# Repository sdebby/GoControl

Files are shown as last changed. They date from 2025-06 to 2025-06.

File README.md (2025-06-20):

# GoControl - ESP32 GoPro remote control

Project start date: 19.10.2024

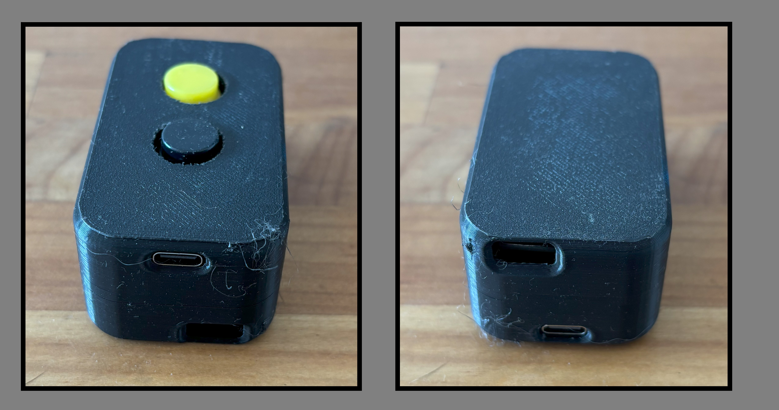
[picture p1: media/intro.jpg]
Overview picture


## Overview

Building a cheap GoPro camera remote control, using Open GoPro API
 
## MRD (Marketing requirement)

 - Creating a simple -easy to use, BLE remote control for GoPro Cameras.
 - up to 2 buttons and LED for operation Indication.
 - Mobile and small size (similar to car remote)
 
### User indications

The remote will indicate the following using build in led:

* On connection - Green LED
* On disconnection - Red LED
* On sending Action Start command - Blue LED
* On sending Camera mode command - Yellow LED
 
## Skill set

 * BLE knowledge.
 * PCB editing.
 * 3D design.
 * 3D printing.
 * Arduino and C++ programming.
 
## BOM (Bill Of Materials):

1. ESP32 C6 dev kit
2. 2 X tact switches.
3. 2 X 330 Ohm resistors.
4. [Charger panel](https://www.aliexpress.com/item/1005005037876729.html?spm=a2g0o.order_list.order_list_main.386.6b881802CcDzO8)
5. LiPo battery 120 mAh.
   
**For R&D:**
1. Wiring.
2. breadboard.

**For production:**
1. PCB manufacturing.
2. 3D printing for enclosure.

## Software:

1. Arduino IDE for coding and uploading to ESP32 C6 board.
2. KiCad for PCB design.
3. Fusion360 for 3D enclosure design

## TSD (Technical Specification)

* Using a BLE to control GoPro camera
[OpenGoPro](https://gopro.github.io/OpenGoPro/ble/index.html)
* Running on ESP32 C6 dev board

## Scheme

1. FOR THE FIRST TIME, AND AFTER INSTALLING NEW FIRMWARE: Insert GoPro camera into [paring model](https://community.gopro.com/s/article/GoPro-Quik-How-To-Pair-Your-Camera?language=en_US#HERO2024)
2. Remote will scan for BLE devices.
3. Remote will connect to the first device that advertise GoPro `serviceUUID` (0xFEA6)
4. On fail connection / disconnection, remote will scan for BLE devices again.
5. Remote will stop scanning and go to deep sleep mode after 3 failed scans.
   1. Remote will wake up on button press.
OnConnection to GoPro camera:
1. Remote will turn BUILTIN LED to Green.
2. On pressing button 1, remote will send Action start command to `COMMAND_REQ_UUID`
3. On releasing button 2, remote will send Action stop command to `COMMAND_REQ_UUID`
4. On pressing button 2, remote will rotate between PhotoMode / VideoMode / TimelapsMode, by sending the correct request to  `COMMAND_REQ_UUID`
5.  The remote will listen to camera reply by registering a listener on  `COMMAND_RSP_UUID` service
OnDisconnection from GoPro camera:
1. Remote will turn BUILTIN LED to Red.
2. Remote will start scanning for GoPro devices again.
3. Remote will go to deep sleep mode after 3 failed scans.

## Schematics

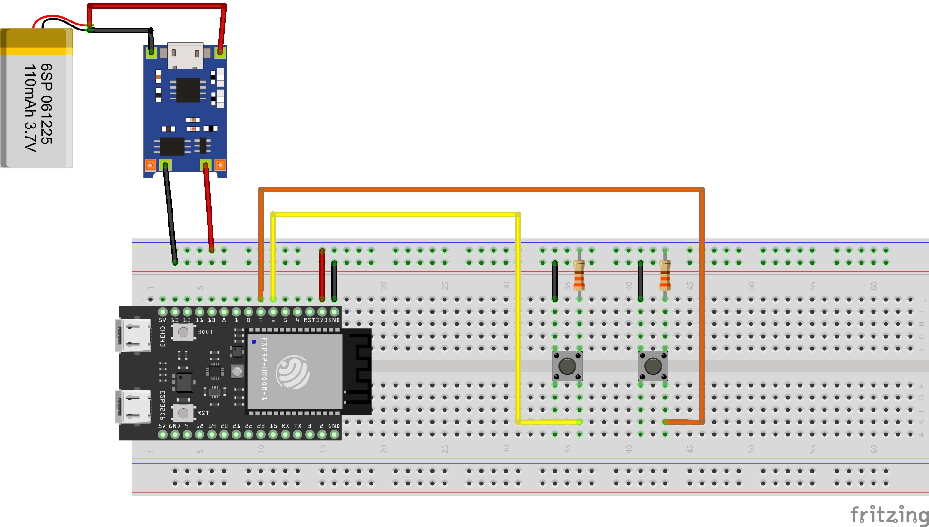
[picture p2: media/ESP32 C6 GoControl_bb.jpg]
Scheme


## PCB

* PCB design using KiCad
* 2 layers PCB
* PCB manufacturing using PCBWay
  
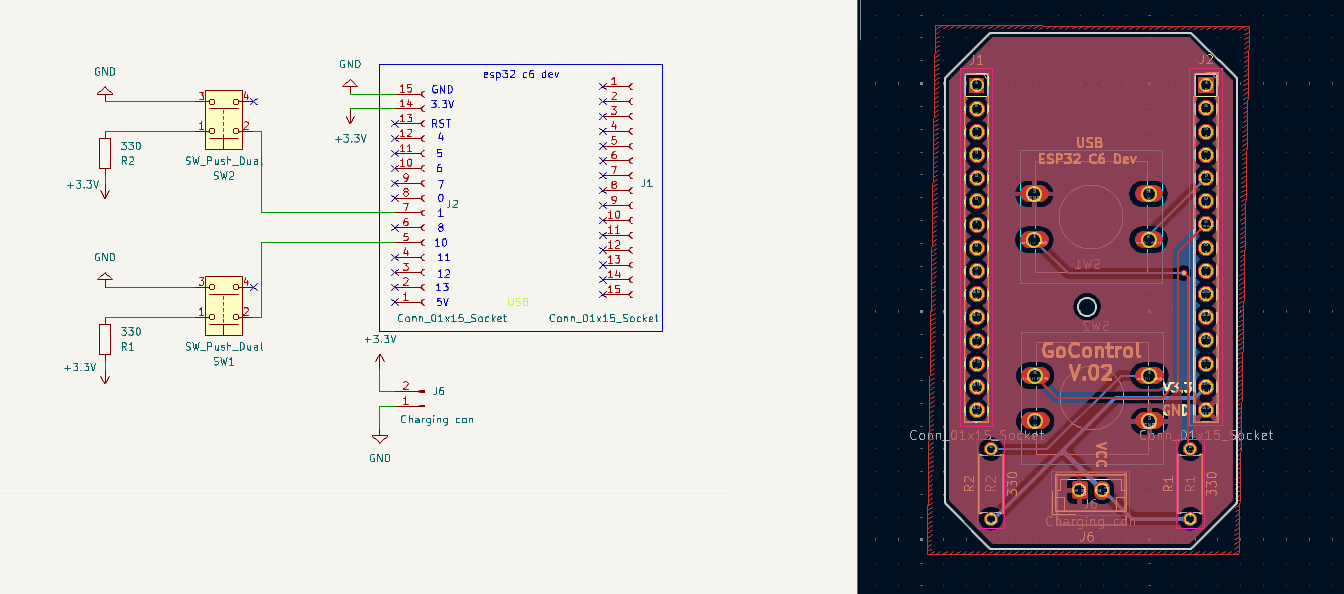
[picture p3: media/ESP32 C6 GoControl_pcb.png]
PCB


## Hardware assembly:

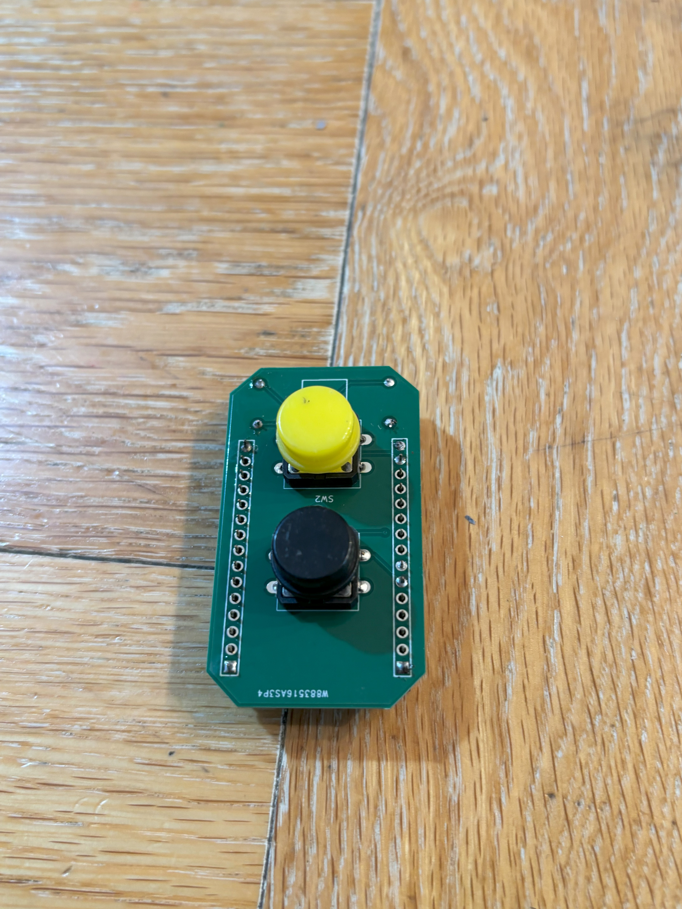
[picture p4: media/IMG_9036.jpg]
Welding components to PCB:


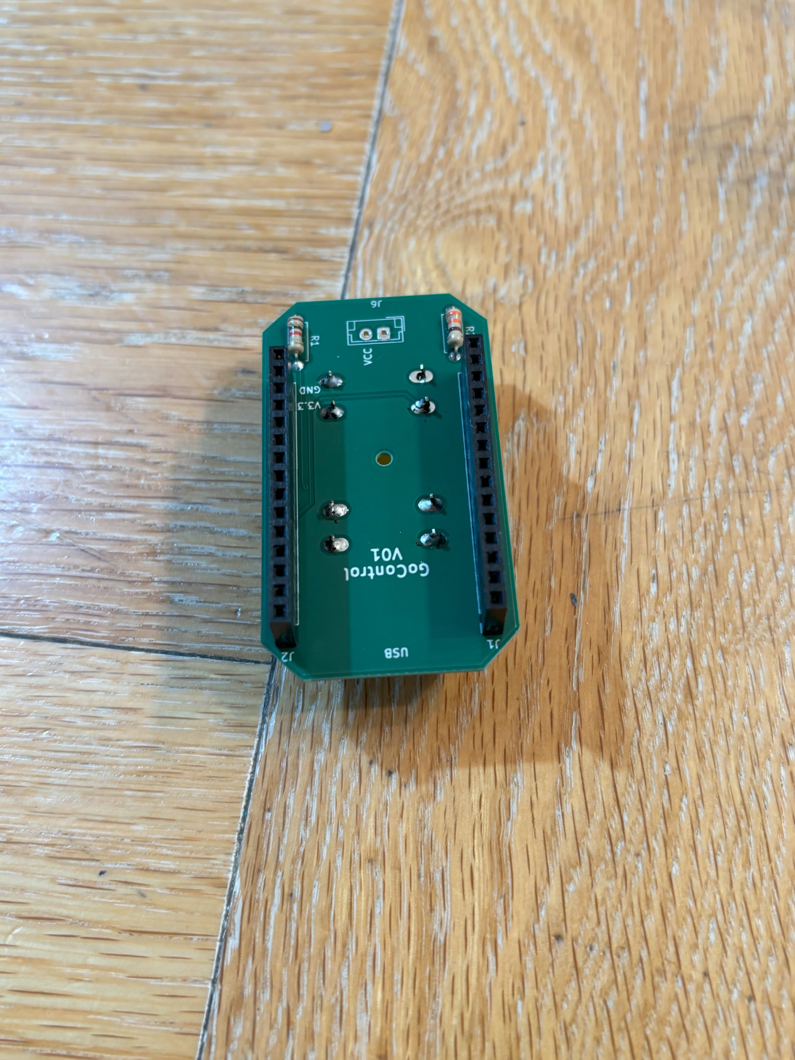
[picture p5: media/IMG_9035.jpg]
Welding components to PCB


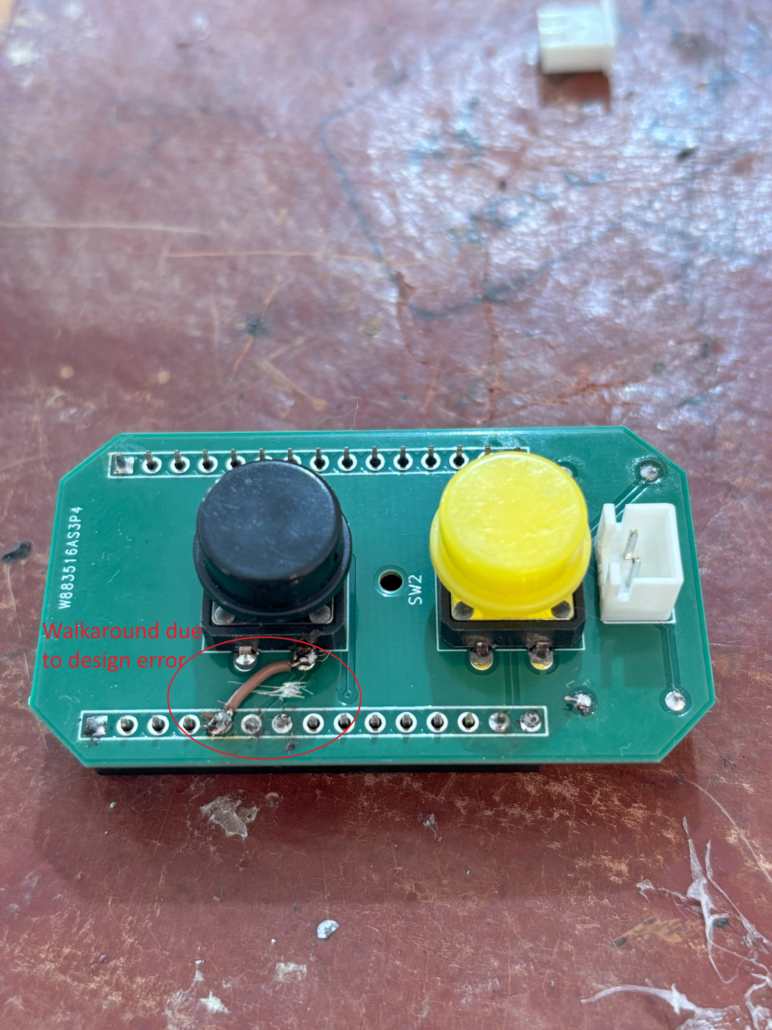
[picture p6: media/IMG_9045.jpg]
Fixing PCB wrong wiring:


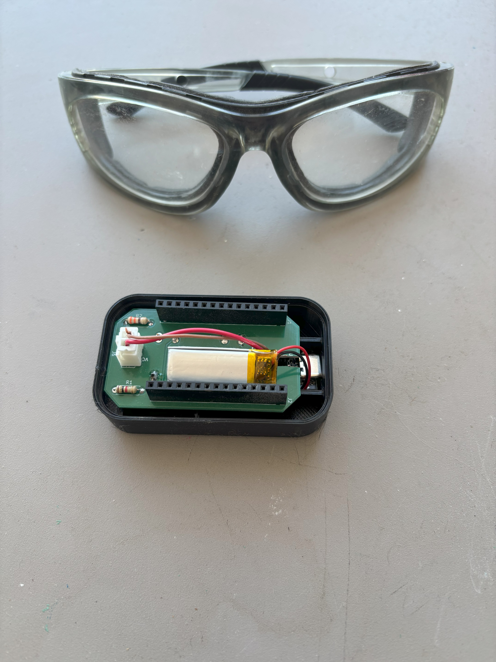
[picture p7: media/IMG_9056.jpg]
Adding cut on PCB to fix ease assembly:


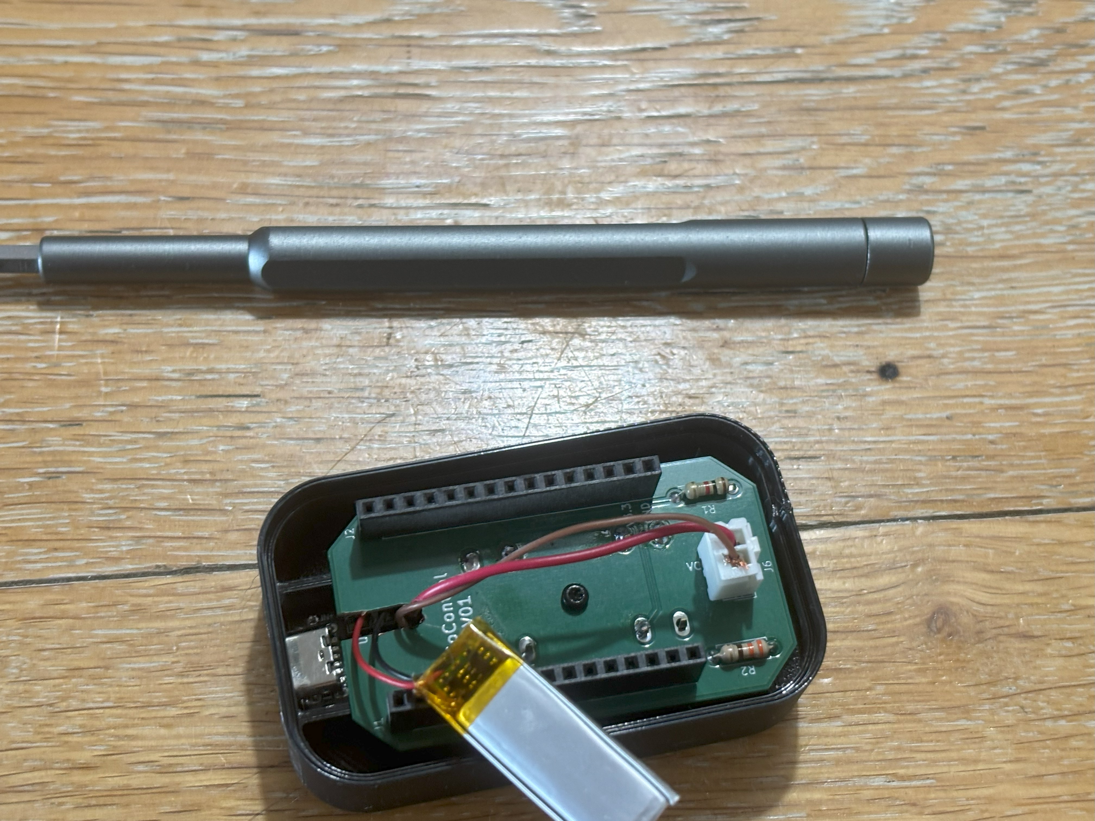
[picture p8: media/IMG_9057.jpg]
Final PCB assembly:


### 3D enclosure design

* using Fusion360
* 3D print using Ender 5 plus with PLA filament.
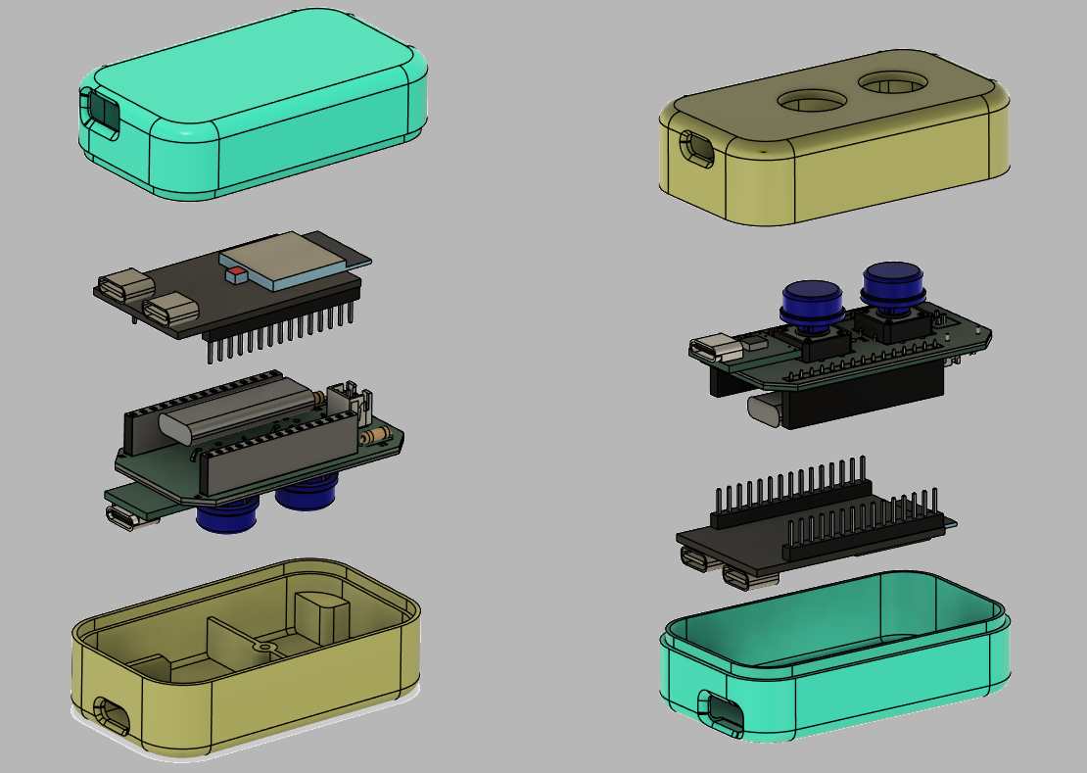
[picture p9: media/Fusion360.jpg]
3D enclosure design


## Video

(https://youtu.be/bjMAEX7DmnI)

## R&D

Coin cell battery capacity:

| Battery | Capacity |
| --- | --- |
|  2016 | 100 mAh |
|  2025 | 170 mAh |
|  2032 | 235 mAh |
|  2450 | 620 mAh |

* Using 2032 battery did not work, as it was not able to power the ESP32 C6 board, I had to use LiPo battery. with 1200 mAh capacity.

### Code fixing

Fixing arduino not displaying BLE device names:
[Fixing library dont support short names](https://github.com/nkolban/esp32-snippets/issues/871)
the file `BLEAdvertisedDevice.cpp` in library :
c:\Users\user1\AppData\Local\Arduino15\packages\esp32\hardware\esp32\3.0.5\libraries\BLE\src\

### Deep sleep

1. deep sleep:
	1. [espressif doc](https://docs.espressif.com/projects/esp-idf/en/latest/esp32c6/api-reference/system/sleep_modes.html)
	2. Wake up on button can be use only on RTC pins
	3. On ESP32-C6: RTC pins are 0-7

## Feedback

If you have any feedback, please reach out to us at mailto:shmulik.debby@gmail.com

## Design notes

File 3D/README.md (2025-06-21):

Project 3D enclosure case files, for 3D FDM printing

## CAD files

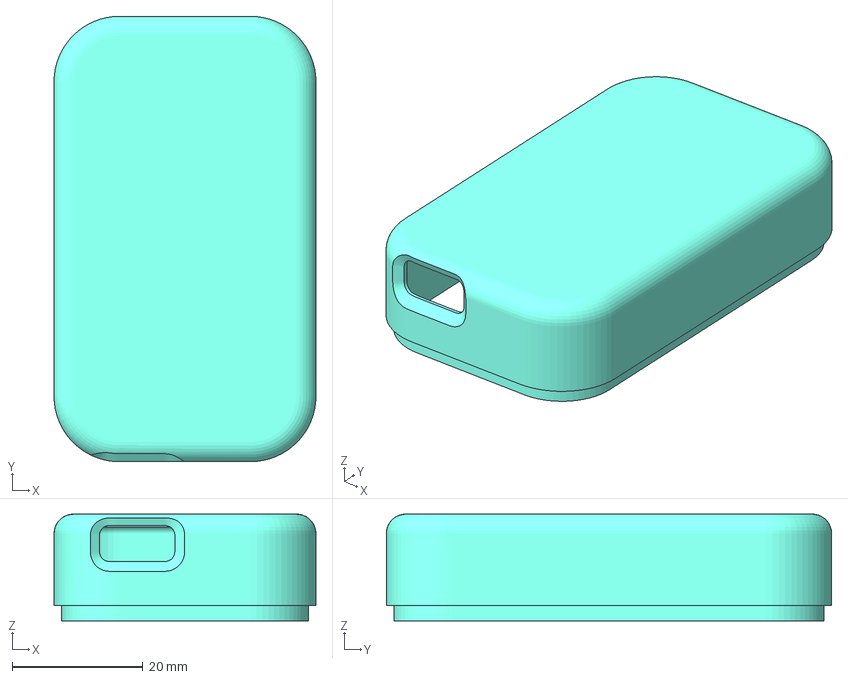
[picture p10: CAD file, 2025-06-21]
3D/Encoder bottom.3mf
40.0 x 68.0 x 16.3 mm

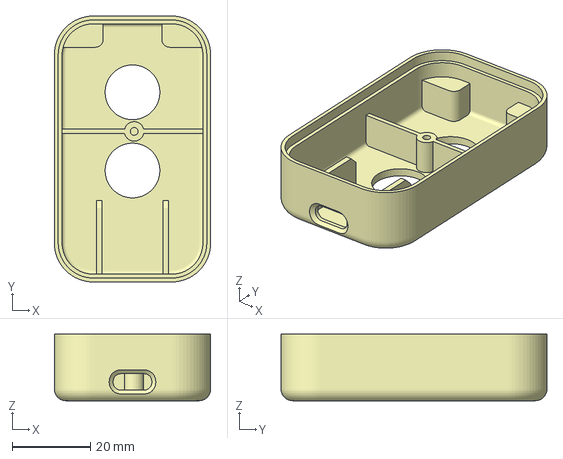
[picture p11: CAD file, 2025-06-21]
3D/Encoder top.3mf
40.0 x 68.0 x 17.0 mm

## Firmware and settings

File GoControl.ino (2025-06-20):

/* 19.10.2024
GoControl - A GoPro remote control camera V.1
*/

#include <BLEDevice.h>
#include <ezButton.h>
#include "driver/rtc_io.h"

#define CONTROL_QUERY_SERVICE_UUID "0000fea6-0000-1000-8000-00805f9b34fb";
uint16_t CONTROL_SERVICE_UUID  = 0xFEA6;
#define INTERNAL_UUID "00002a19-0000-1000-8000-00805f9b34fb"

#define WIFI_AP_SSID_UUID "b5f90002-aa8d-11e3-9046-0002a5d5c51b"
#define WIFI_AP_PASSWORD_UUID "b5f90003-aa8d-11e3-9046-0002a5d5c51b"

#define COMMAND_REQ_UUID "b5f90072-aa8d-11e3-9046-0002a5d5c51b"
#define COMMAND_RSP_UUID "b5f90073-aa8d-11e3-9046-0002a5d5c51b"
#define SETTINGS_REQ_UUID "b5f90074-aa8d-11e3-9046-0002a5d5c51b"
#define SETTINGS_RSP_UUID "b5f90075-aa8d-11e3-9046-0002a5d5c51b"
#define QUERY_REQ_UUID "b5f90076-aa8d-11e3-9046-0002a5d5c51b"
#define QUERY_RSP_UUID "b5f90077-aa8d-11e3-9046-0002a5d5c51b"

#define NETWORK_MANAGEMENT_REQ_UUID "b5f90091-aa8d-11e3-9046-0002a5d5c51b"
#define NETWORK_MANAGEMENT_RSP_UUID "b5f90092-aa8d-11e3-9046-0002a5d5c51b"

bool GoProFound = false;
bool IsConnected = false;
BLEScan *pBLEScan;
int scanTime = 5;  //In seconds
static BLEAdvertisedDevice *GoProAddress;
static BLERemoteCharacteristic *pRemoteCharacteristicREQ; //Request UUID
static BLERemoteCharacteristic *pRemoteCharacteristicRSP; // Responce UUID
byte ActionStart[] = {0x03, 0x01, 0x01, 0x01};  
byte ActionStop[] = {0x03, 0x01, 0x01, 0x00};  

byte PhotoMode[] = {0x04, 0x3E, 0x02, 0x03, 0xE9};  
byte VideoMode[] = {0x04, 0x3E, 0x02, 0x03, 0xE8};  
byte TimelapsMode[] = {0x04, 0x3E, 0x02, 0x03, 0xEA};  
int CamMode = 0; // Camera mode - 0 = Photo, 1 = Video, 2 = Timelaps
int DisconnectCount = 0; //Count no of disconnections
int NoOfScans = 3; // BLE scans before going to deep sleep
int ScanDone = 0; // Number of BLE scans that done

ezButton Button_1(1,INPUT_PULLUP);
ezButton Button_2(10,INPUT_PULLUP);

static BLEUUID serviceUUID(CONTROL_SERVICE_UUID);
static BLEUUID charUUID_REQ(COMMAND_REQ_UUID);
static BLEUUID charUUID_RSP(COMMAND_RSP_UUID);

// Deep sleep parameters
#define BUTTON_PIN_BITMASK(GPIO) (1ULL << GPIO)  // 2 ^ GPIO_NUMBER in hex
#define USE_EXT0_WAKEUP 1               // 1 = EXT0 wakeup, 0 = EXT1 wakeup
#define WAKEUP_GPIO GPIO_NUM_7     // Wateup pin
bool Wakup_RTC_CNTL = false;

// Wakeup reason
void print_wakeup_reason() {
  esp_sleep_wakeup_cause_t wakeup_reason;
  wakeup_reason = esp_sleep_get_wakeup_cause();
  switch (wakeup_reason) {
    case ESP_SLEEP_WAKEUP_EXT1:
      Serial.println("Wakeup caused by external signal using RTC_CNTL");
      Wakup_RTC_CNTL = true;
      break;
    default:
      Serial.printf("Wakeup was not caused by deep sleep: %d\n", wakeup_reason);
      break;
  }
}


class ClientCallback : public BLEClientCallbacks {
  void onConnect(BLEClient *pclient) {
    Serial.println("onCOnnect");
  }

  void onDisconnect(BLEClient *pclient) {
    Serial.println("onDisconnect");
    IsConnected = false;
  }
};

// Notify callback
static void notifyCallback(BLERemoteCharacteristic *pBLERemoteCharacteristic, uint8_t *pData, size_t length, bool isNotify) {
  Serial.print("[*] Notify callback, data length: ");
  Serial.print(length);
  Serial.print(" ,data: ");
  for (int i = 0; i < length ; i++){
    if(pData[i] < 9){
      Serial.print("0");
    }
    Serial.print(pData[i], HEX);
    Serial.print(" ");
  }
  Serial.println();
}

// Connect to BLE Server
void ConnectToBLE() {
  Serial.print("[*] Connecting to: ");
  Serial.println(GoProAddress->getAddress().toString().c_str());
  BLEClient *pClient = BLEDevice::createClient();
  pClient->setClientCallbacks(new ClientCallback());
  BLEDevice::setEncryptionLevel(ESP_BLE_SEC_ENCRYPT);
  pClient->connect(GoProAddress); 
  if (!pClient->isConnected()) { // Check if connected
    Serial.println("[X] Client not connected.");
    return;
  }
  pClient->setMTU(517);  //set client to request maximum MTU from server (default is 23 otherwise)
  Serial.println("[V] Connected to GoPro camera");
  RGBLed('g');
  Serial.println("[*] Attempting to connect to service...");
    
  BLERemoteService *pRemoteService = pClient->getService(serviceUUID);  // Obtain a reference to the service we are after in the remote BLE server.
  if (pRemoteService == nullptr) {
    Serial.print("[X] Failed to find SERVICE UUID: ");
    Serial.println(serviceUUID.toString().c_str());
    pClient->disconnect();
  } else {
    Serial.println("[V] Connected to SERVICE UUID");
    // CONNECTING TO REQUEST uuid
      pRemoteCharacteristicREQ = pRemoteService->getCharacteristic(charUUID_REQ); //request UUID
      if (pRemoteCharacteristicREQ == nullptr) {
        Serial.println("[X] Failed to find REQUEST Characteristic UUID: ");
        pClient->disconnect();
      } else{
        Serial.println("[V] Connected to REQUEST Characteristic UUID");
        IsConnected = true;
      }
    // CONNECTING TO RESPONCE uuid
      pRemoteCharacteristicRSP = pRemoteService->getCharacteristic(charUUID_RSP); //responce UUID
      if (pRemoteCharacteristicRSP == nullptr) {
        Serial.println("[X] Failed to find RESPONCE Characteristic UUID: ");
        pClient->disconnect();
      } else{
        pRemoteCharacteristicRSP->registerForNotify(notifyCallback);
        Serial.println("[V] Registering RESPONCE UUID");
      }
  }
}

class MyAdvertisedDeviceCallbacks : public BLEAdvertisedDeviceCallbacks {
  void onResult(BLEAdvertisedDevice advertisedDevice) {
      Serial.print("[*] Device Name: ");
      Serial.print(advertisedDevice.getName().c_str());
      Serial.print(", MAC Address: ");
      Serial.println(advertisedDevice.getAddress().toString().c_str());
    if (advertisedDevice.haveServiceUUID() && advertisedDevice.isAdvertisingService(serviceUUID)) { //search for service UUID instead of name
      pBLEScan->stop(); //stop scan
      Serial.println("[V] device found !");
      GoProFound = true;
      GoProAddress = new BLEAdvertisedDevice(advertisedDevice);
    }
  }
};

// Scan BLE devices
void scanBLEDevices() {
  Serial.println("[*] Scanning for BLE devices...");
  pBLEScan = BLEDevice::getScan();  //create new scan
  pBLEScan->setAdvertisedDeviceCallbacks(new MyAdvertisedDeviceCallbacks());
  pBLEScan->setActiveScan(true);  //active scan uses more power, but get results faster
  pBLEScan->setInterval(1349);
  pBLEScan->setWindow(449);  // less or equal setInterval value
  pBLEScan->setActiveScan(true);
  BLEScanResults *foundDevices = pBLEScan->start(scanTime, false);
  Serial.print("[*] Devices found: ");
  Serial.println(foundDevices->getCount());
  Serial.println("[*] Scan complete !"); 
  }

void setup() {

  Serial.begin(115200);
  Serial.println("-- GoControl --");
  RGBLed('o');
    //Print the wakeup reason for ESP32
    print_wakeup_reason();
    //deep sleep setup
    esp_sleep_enable_ext1_wakeup_io(BUTTON_PIN_BITMASK(WAKEUP_GPIO), ESP_EXT1_WAKEUP_ANY_LOW); 
    rtc_gpio_pulldown_en(WAKEUP_GPIO);  // GPIO7 is tie to GND in order to wake up in HIGH
    rtc_gpio_pullup_dis(WAKEUP_GPIO);   // Disable PULL_UP in order to allow it to wakeup on HIGH
  BLEDevice::init("");

  while  (!GoProFound){
    scanBLEDevices(); // Scan devices
    if (GoProFound){ // Device found after scaning    
      ConnectToBLE();
      ScanDone == 0;
    } else {
      Serial.print("[X] No GoPro camera found, Scans done: ");
      Serial.println(ScanDone);
      delay(500); 
      if (ScanDone == NoOfScans ){ //Go to sleep
        Serial.println("[*] Device going to deep sleep");
        esp_deep_sleep_start();
      }
      ScanDone ++; //TODO fix first button press after awake
    }
  }
}

void loop() {
  Button_1.loop();
  Button_2.loop();
  if (IsConnected){
    DisconnectCount == 0;
    // Button 1
    if(Button_1.isPressed()){
      Serial.println("[*] Button_1 pressed");
      pRemoteCharacteristicREQ->writeValue(ActionStart,sizeof(ActionStart)); //write value to camera
      RGBLed('b');
    }

    if(Button_1.isReleased()){
      Serial.println("[*] Button_1 released");
      if (Wakup_RTC_CNTL){ // Check if button pressed to wake up controller
        Wakup_RTC_CNTL = false;
      } else {
        pRemoteCharacteristicREQ->writeValue(ActionStop,sizeof(ActionStop)); //write value to camera
        delay(200);
        RGBLed('g');
      }
    }

    // Burron 2
    if(Button_2.isPressed()){
      Serial.println("[*] Button_2 pressed");
      switch (CamMode) {
      case 0:
        CamMode = 1;
        pRemoteCharacteristicREQ->writeValue(VideoMode,sizeof(VideoMode)); //write value to camera
        break;
      case 1:
        CamMode = 2;
        pRemoteCharacteristicREQ->writeValue(TimelapsMode,sizeof(TimelapsMode)); //write value to camera
        break;
      case 2:
        CamMode = 0; 
        pRemoteCharacteristicREQ->writeValue(PhotoMode,sizeof(PhotoMode)); //write value to camera
        break;
      }
    Serial.print("[*] CamMode :");
    Serial.println(CamMode);
    RGBLed('y');
    }

    if(Button_2.isReleased()){
      Serial.println("[*] Button_2 released");
      delay(200);
      RGBLed('g');
    }
  } else {
      Serial.print("[X] Camera not connected, scan count :");
      Serial.println(DisconnectCount);
      RGBLed('r');
      DisconnectCount ++;
      if (DisconnectCount < 5) { // Retry to connect 5 times, then go to sleep
        ConnectToBLE();
      } else {
        RGBLed('o');
        delay(200);
        Serial.println("[*] Device going to deep sleep");
        esp_deep_sleep_start();
      }
  }

  delay(200);
}

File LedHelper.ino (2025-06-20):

  /* Led helper
  Led colors
  r - red
  g - green
  b - blue
  y - yellow
  w - white
  p - pink
  a - amber
  o - black
  */

void RGBLed(char l3d){

  switch (l3d) {
    case 'r':
      rgbLedWrite(RGB_BUILTIN, RGB_BRIGHTNESS, 0 ,0);   // Turn the RGB LED red
      break;
    case 'g':
      rgbLedWrite(RGB_BUILTIN, 0, RGB_BRIGHTNESS ,0);   // Turn the RGB LED green
      break;
    case 'b':
      rgbLedWrite(RGB_BUILTIN, 0, 0 ,RGB_BRIGHTNESS);   // Turn the RGB LED blue
      break;
    case 'y':
      rgbLedWrite(RGB_BUILTIN, 255, 255 ,0);   // Turn the RGB LED yellow
      break;
    case 'w':
      digitalWrite(RGB_BUILTIN, HIGH);   // Turn the RGB LED white
      break;
    case 'o':
      digitalWrite(RGB_BUILTIN, LOW);   // Turn the RGB LED white
      break;
    case 'p':
      rgbLedWrite(RGB_BUILTIN, 224, 33 ,38);   // Turn the RGB LED Pink
      break;
    case 'a':
      rgbLedWrite(RGB_BUILTIN, 255, 126 ,0);   // Turn the RGB LED Amber
      break;

    default:
      Serial.println("Select r, g, b, w, y,  o");
      break;
  }
}
